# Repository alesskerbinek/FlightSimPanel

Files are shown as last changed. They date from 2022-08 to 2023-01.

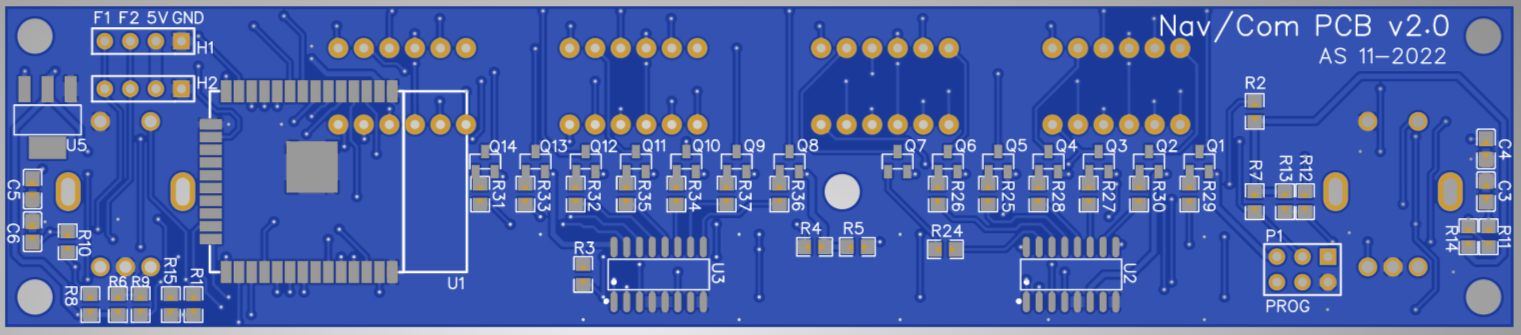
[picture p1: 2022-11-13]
Hardware/NavCom/PCB/v2/v2.0_Bottom.PNG

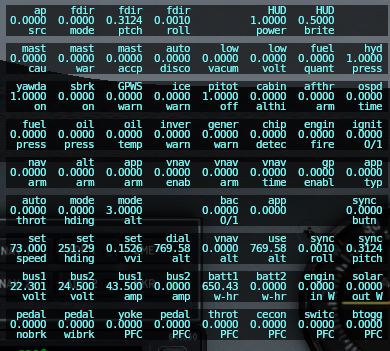
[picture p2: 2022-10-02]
Scratch/DATA2.JPG

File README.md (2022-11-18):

# FlightSimPanel

This is the main directory for FlightSimPanel project. For detailed description please read the [Wiki](https://github.com/alesskerbinek/FlightSimPanel/wiki) pages.

The directory structure is as follows:
<pre>
.
├── Scratch         # Ideas and notes
├── Hardware
│    ├── NavCom     # VOR/Radio/ADF/XPNDR unit
│    │    ├── PCB
│    │    │    ├── v1
│    │    │    └── v2
│    │    └── Case
│    ├── Audio*     # Audio Panel unit
│    │    ├── PCB*
│    │    └── Case*
│    └── Autopilot* # Autopilot Control unit
│         ├── PCB*
│         └── Case*
└── Software
     ├── NavCom     # VOR/Radio/ADF/XPNDR unit
     ├── Common     # Common files
     ├── Audio*     # Audio Panel unit
     └── Autopilot* # Autopilot Control unit
     
* - TODO
</pre>

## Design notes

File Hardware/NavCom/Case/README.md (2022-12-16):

In this directory we find Case/Housing related project files.

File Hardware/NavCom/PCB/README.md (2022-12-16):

In this directory we find PCB related project files.

PCB revisions are separated in multiple subdirectories.

You can preview Gerber files on: https://www.pcbway.com/project/OnlineGerberViewer.html

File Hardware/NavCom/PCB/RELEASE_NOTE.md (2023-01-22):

v1.0
* initial version

v2.0
* Increased clearance around holes (moving resistors)
* Extended width of power lines between I2C headers (due to daisy chaining)
* Renaming data lines on I2C headers to F1 & F2
* Buttons footprint changed to SMD that fits both switches and tactile pushbuttons
* Diode footprint modified to support bigger size component
* Button positions changed
* Added LED to tell status of unit (connected to sim)
* Additional bolt fix point in the middle of the board

v2.1
* minor fixes on the schematics only (comments and resistors R15, R38 values changed)

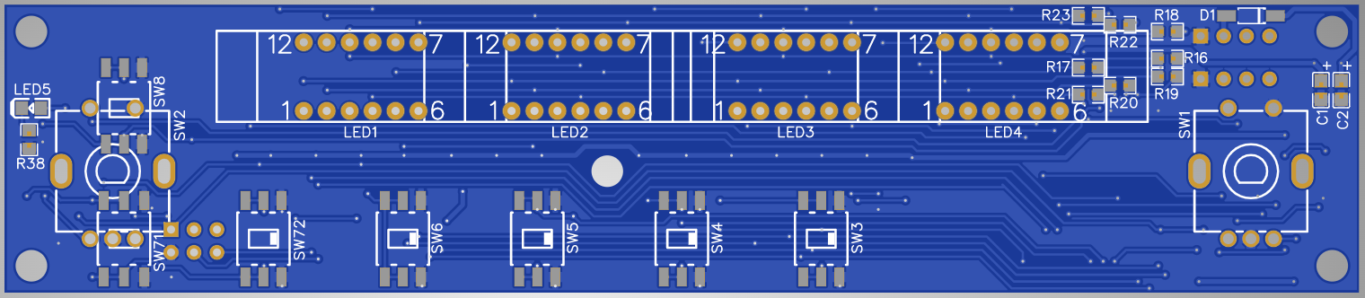
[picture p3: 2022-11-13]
Hardware/NavCom/PCB/v2/v2.0_Top.PNG

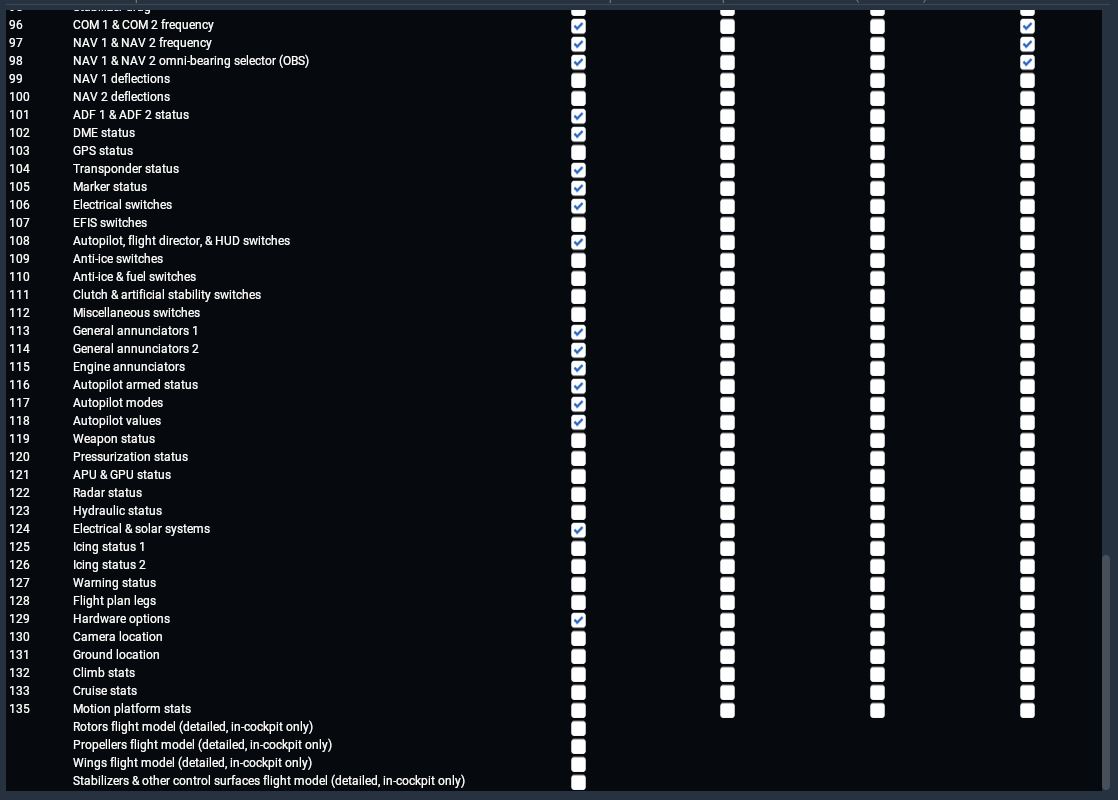
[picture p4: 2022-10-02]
Scratch/DATA0.JPG

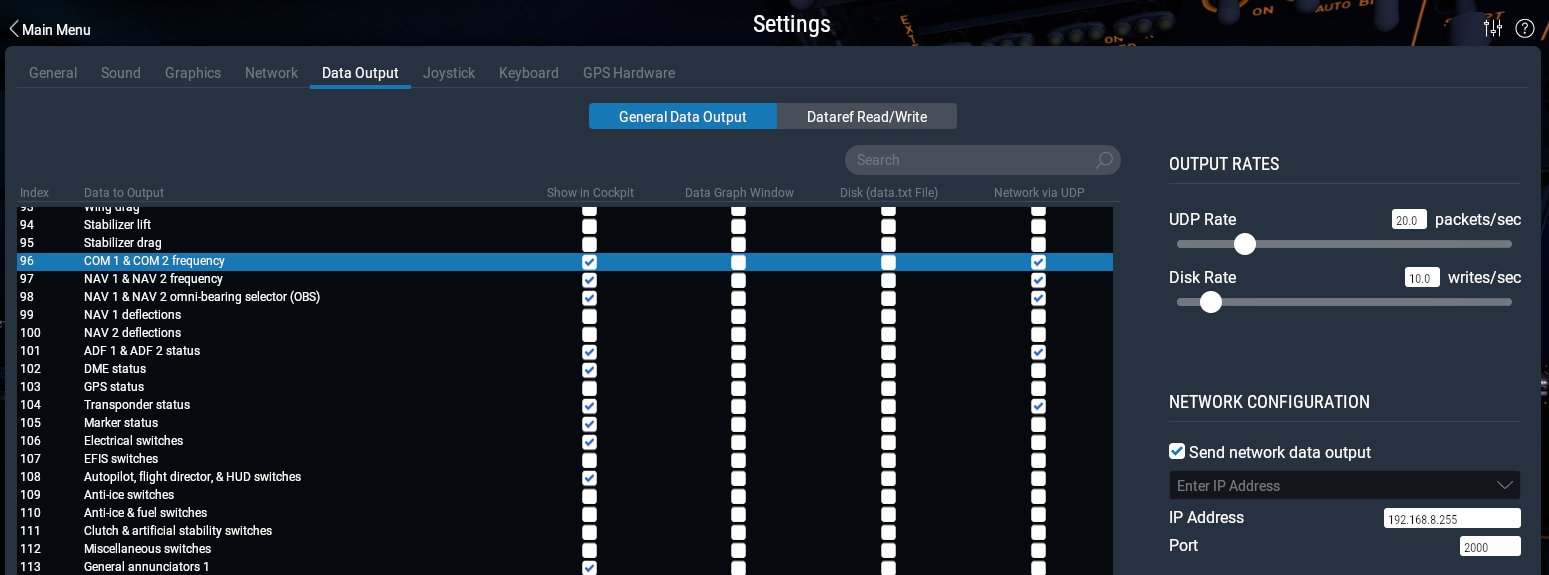
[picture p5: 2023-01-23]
Docu/Resource/data-config.PNG

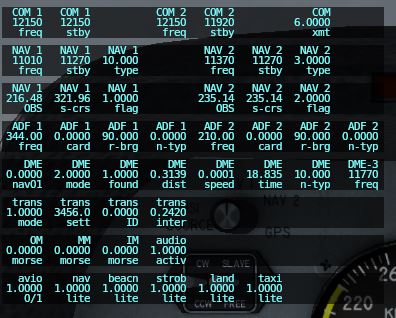
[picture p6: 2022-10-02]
Scratch/DATA1.JPG

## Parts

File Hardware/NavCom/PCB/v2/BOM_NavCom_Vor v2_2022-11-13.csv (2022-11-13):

ID | Name | Designator | Footprint | Quantity | Manufacturer Part | Manufacturer | Supplier | Supplier Part | Price
1 | 10u | C1,C2 | C0805 | 2
2 | 220n | C3,C4,C5,C6 | C0805 | 4
3 | 1N4007 | D1 | SOD-123_L2.8-W1.8-LS3.7-RD | 1 | 1N4007W | BLUE ROCKET | LCSC | C328592 | 0.011
4 | HDR-F-2.54 | H1,H2 | HDR-F-2.54_1X4 | 2 |  |  | LCSC | C239342 | 0.089
5 | 2481BS | LED1,LED2,LED3,LED4 | 7-SEGMENT_2481BS | 4 | MHDA3641SRBW | MEIHUA | LCSC | C401125 | 1.041
6 | LED-Red(0805) | LED5 | LED-0805 | 1 | 17-21SURC/S530-A2/TR8 | Everlight Elec | LCSC | C131244 | 0.02
7 | HDR-2.54-2X3P | P1 | HDR-F-2.54_2X3 | 1 | 2X3 2.54mm IDC Box | BOOMELE | LCSC | C11214 | 0.09
8 | BC807-40LVL | Q1,Q2,Q3,Q4,Q5,Q6,Q7,Q8,Q9,Q10,Q11,Q12,Q13,Q14 | SOT-23-3_L2.9-W1.3-P1.90-LS2.4-BR | 14 | BC807-40LVL | Nexperia | LCSC | C549409 | 0.024
9 | 10k | R1,R2,R3,R4,R5,R6,R7,R8,R9,R10,R11,R12,R13,R14,R15,R38 | R0805 | 16
10 | 220 | R16,R17,R18,R19,R20,R21,R22,R23 | R0805 | 8
11 | 1K | R24,R25,R26,R27,R28,R29,R30,R31,R32,R33,R34,R35,R36,R37 | R0805 | 14
12 | PEC11R | SW1,SW2 | SW-TH_PEC11R-4XXXF-SXXXX | 2 | PEC11R-4015F-S0024 | BOURNS | LCSC | C143789 | 1.67
13 | K8-5851E-L1 | SW3,SW4,SW5,SW6,SW8,SW71,SW72 | SW-TH_6P-L5.8-W5.8-P2.00-LS4.5-BL | 7 | K8-5851E-L1 | HRO | LCSC | C111760 | 0.2
14 | ESP32-WROOM-32D-H4 | U1 | WIFIM-SMD_ESP32-WROOM-32D | 1 | ESP32-WROOM-32D-H4 | ESPRESSIF 乐鑫 | LCSC | C3013936 | 3.336
15 | 74HC138D | U2,U3 | SOIC-16_L9.9-W3.9-P1.27-LS6.0-BL | 2 | 74HC138D | TOSHIBA(东芝) | LCSC | C2674688 | 0.147
16 | NCP1117ST33T3G | U5 | SOT-223-3_L6.5-W3.4-P2.30-LS7.0-BR | 1 | NCP1117ST33T3G | ON | LCSC | C26537 | 0.311

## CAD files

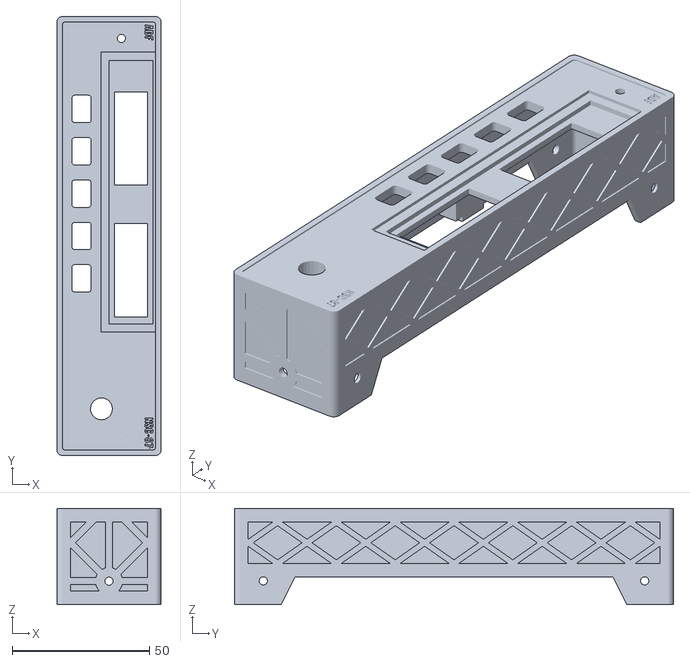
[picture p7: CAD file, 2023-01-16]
Hardware/NavCom/Case/ADF-case.stl
38.0 x 160.0 x 35.0

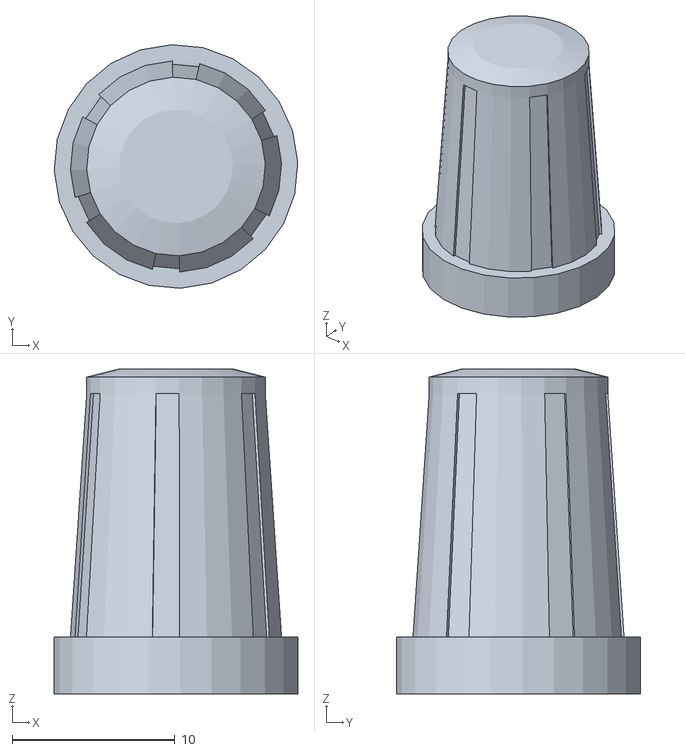
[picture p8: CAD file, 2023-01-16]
Hardware/NavCom/Case/Knob-empty.stl
15.0 x 15.0 x 20.0

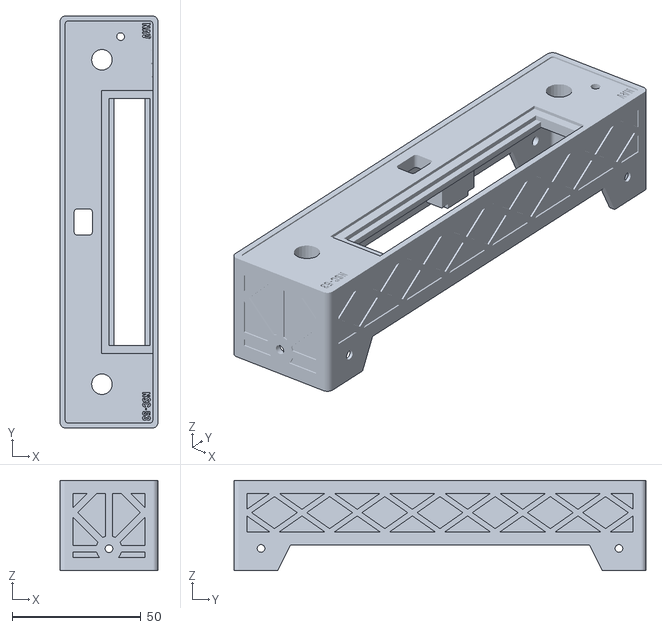
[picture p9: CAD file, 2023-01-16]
Hardware/NavCom/Case/NAV-case.stl
38.0 x 160.0 x 35.0

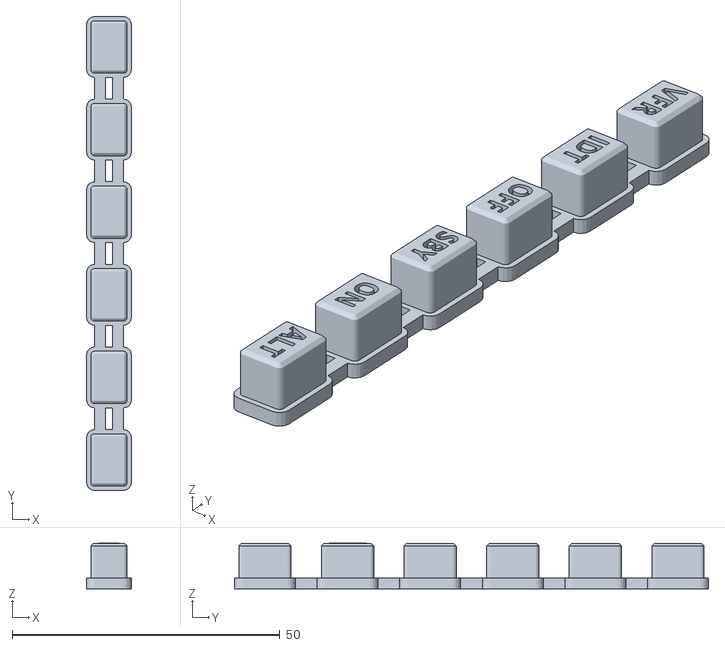
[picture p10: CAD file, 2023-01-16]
Hardware/NavCom/Case/XPNDR-buttons.stl
8.40 x 88.6 x 8.52

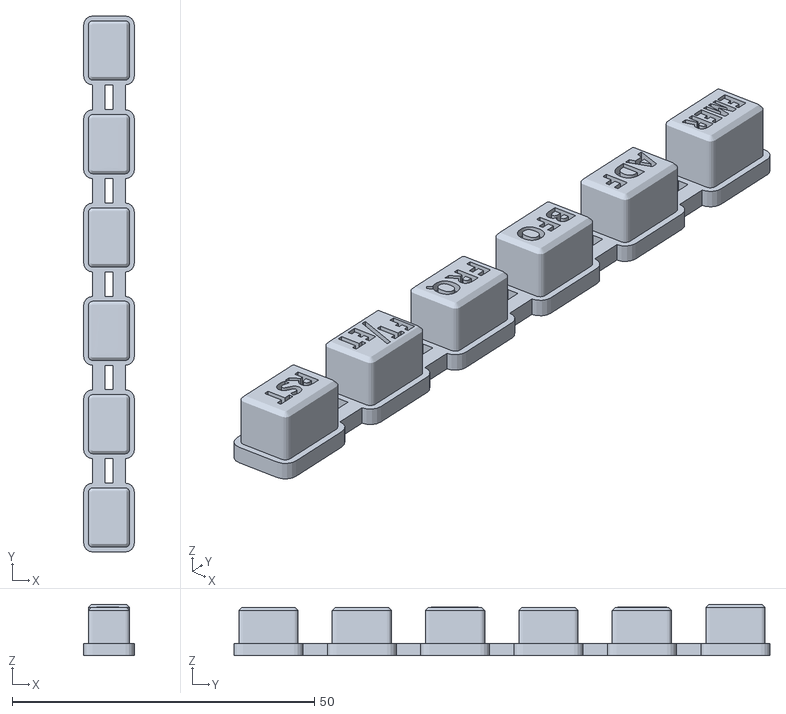
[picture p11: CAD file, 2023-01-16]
Hardware/NavCom/Case/ADF-buttons.stl
8.40 x 88.7 x 8.50

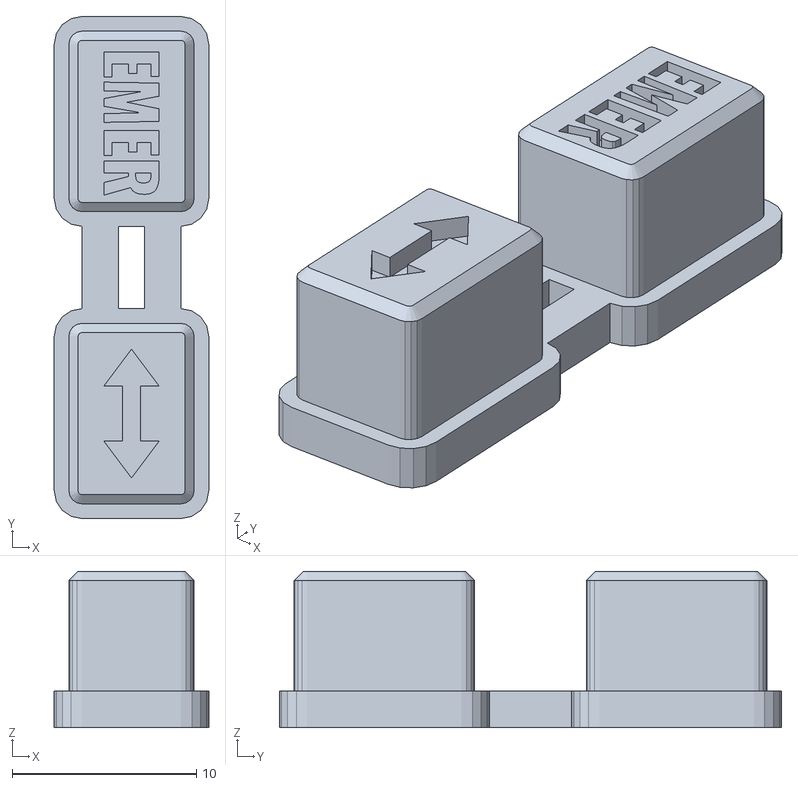
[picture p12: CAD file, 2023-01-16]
Hardware/NavCom/Case/COM-buttons.stl
8.40 x 27.3 x 8.50

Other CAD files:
Hardware/NavCom/Case/XPNDR-case.stl
Hardware/NavCom/Case/Knob-OBS.stl
Hardware/NavCom/Case/Knob-volume.stl
Hardware/NavCom/Case/COM-case.stl
Hardware/NavCom/Case/ADF-buttons.skp
Hardware/NavCom/Case/ADF-case.skp
Hardware/NavCom/Case/COM-buttons.skp
Hardware/NavCom/Case/COM-case.skp
Hardware/NavCom/Case/Knob-OBS.skp
Hardware/NavCom/Case/Knob-empty.skp
Hardware/NavCom/Case/Knob-volume.skp
Hardware/NavCom/Case/NAV-case.skp
Hardware/NavCom/Case/XPNDR-buttons.skp
Hardware/NavCom/Case/XPNDR-case.skp

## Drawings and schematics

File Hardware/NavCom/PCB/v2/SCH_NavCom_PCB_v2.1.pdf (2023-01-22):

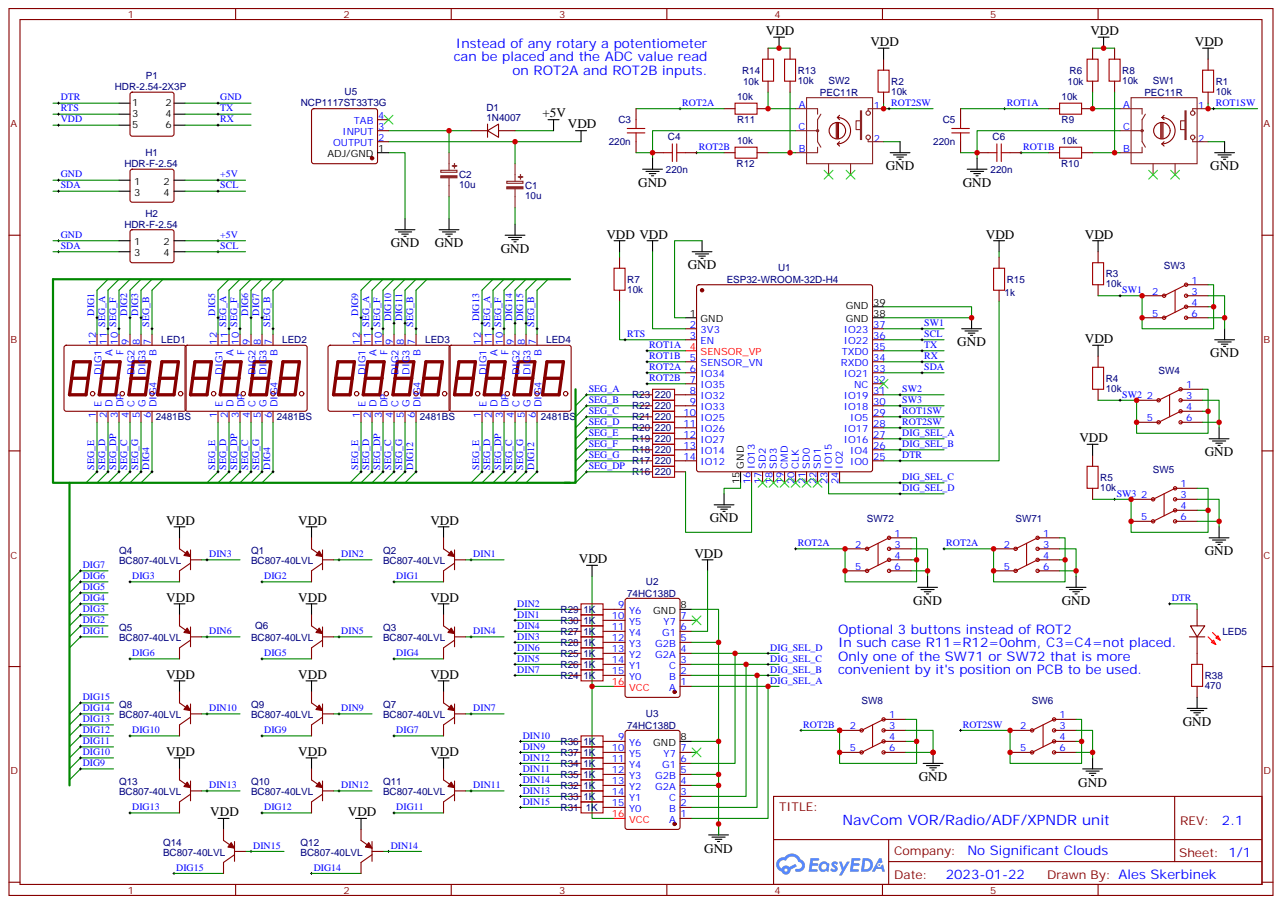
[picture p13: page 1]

Instead of any rotary a potentiometer
can be placed and the ADC value read

Optional 3 buttons instead of ROT2
In such case R11=R12=0ohm, C3=C4=not placed.
Only one of the SW71 or SW72 that is more
convenient by it's position on PCB to be used.

Company: No Significant Clouds

Drawn By: Ales Skerbinek

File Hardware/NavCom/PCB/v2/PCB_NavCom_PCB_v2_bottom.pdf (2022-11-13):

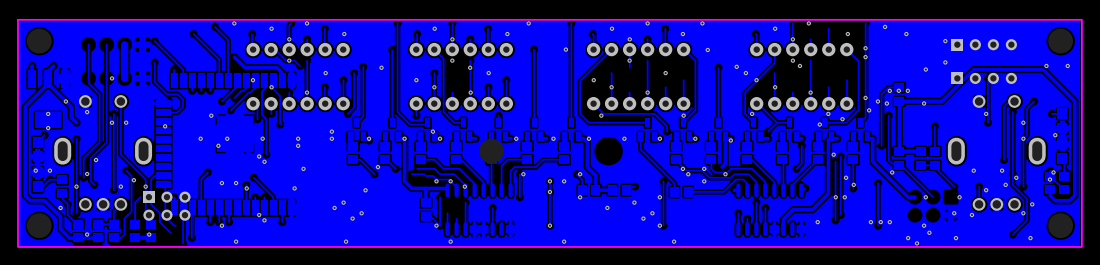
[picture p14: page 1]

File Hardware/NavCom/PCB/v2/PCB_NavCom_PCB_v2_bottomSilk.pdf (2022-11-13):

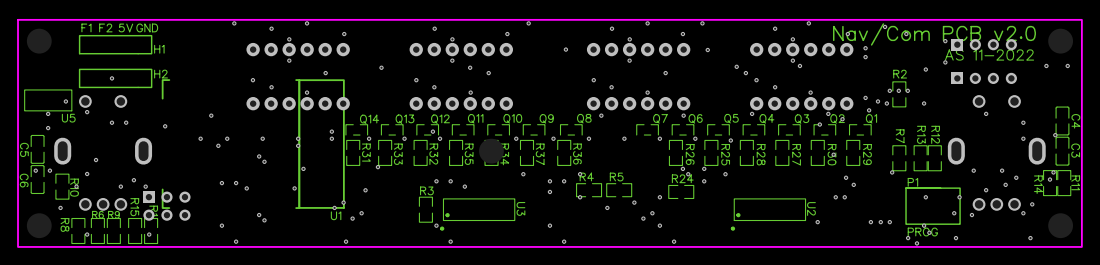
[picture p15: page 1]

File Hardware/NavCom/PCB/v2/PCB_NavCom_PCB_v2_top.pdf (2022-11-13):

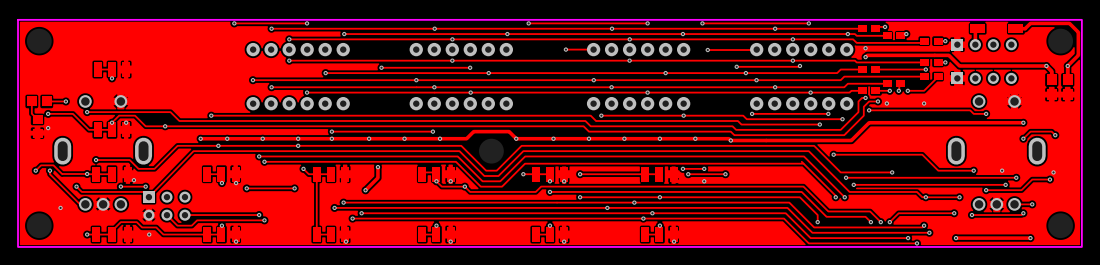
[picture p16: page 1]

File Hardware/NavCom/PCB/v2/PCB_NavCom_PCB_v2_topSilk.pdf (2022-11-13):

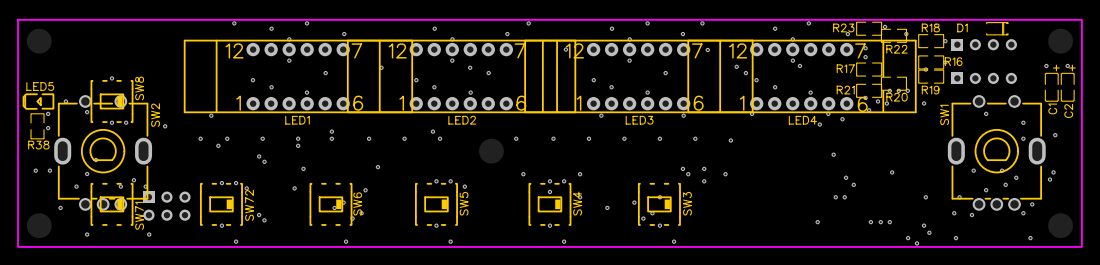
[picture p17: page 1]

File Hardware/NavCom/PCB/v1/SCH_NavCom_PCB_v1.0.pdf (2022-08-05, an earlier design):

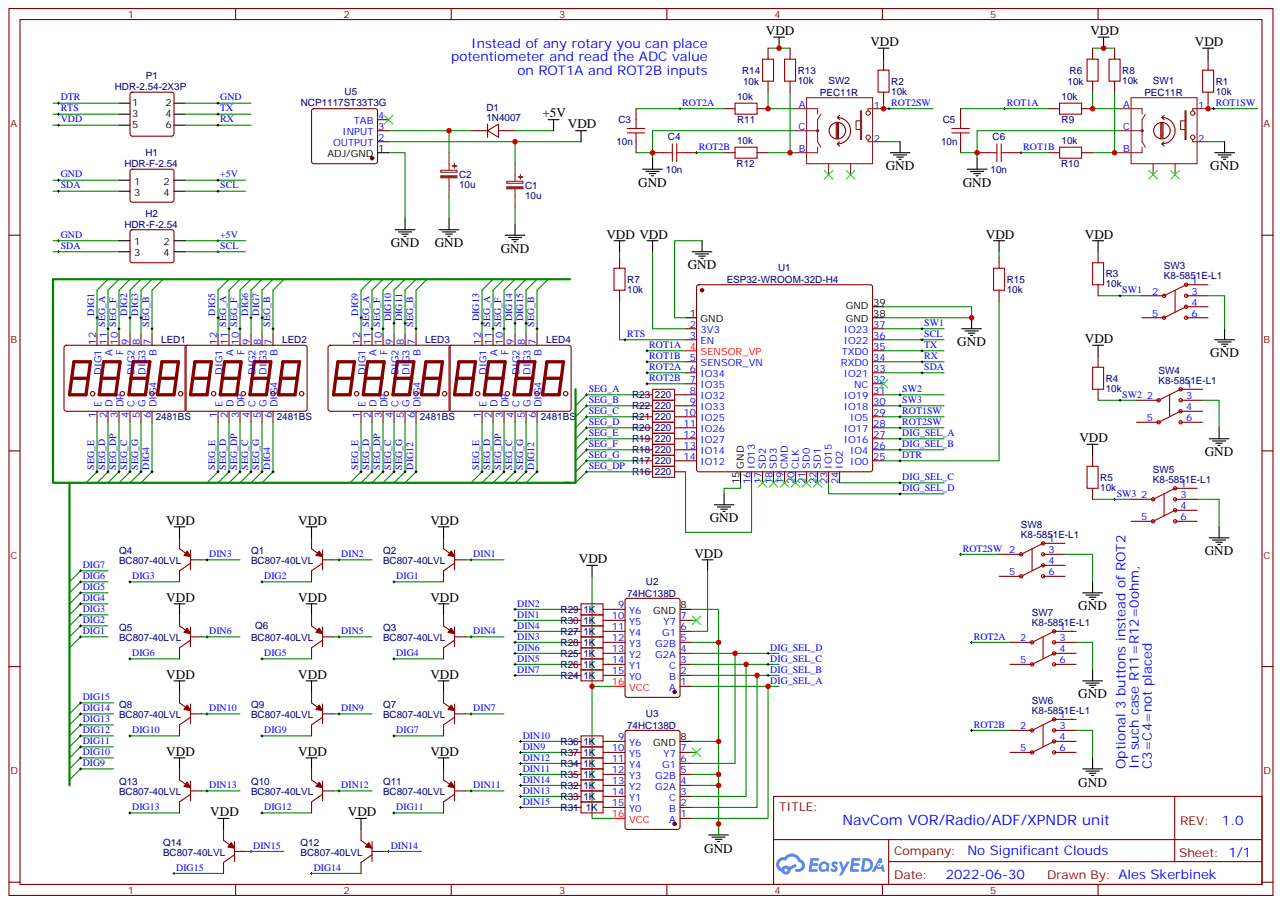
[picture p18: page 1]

Instead of any rotary you can place
potentiometer and read the ADC value

Optional 3 buttons instead of ROT2

Company: No Significant Clouds

Drawn By: Ales Skerbinek

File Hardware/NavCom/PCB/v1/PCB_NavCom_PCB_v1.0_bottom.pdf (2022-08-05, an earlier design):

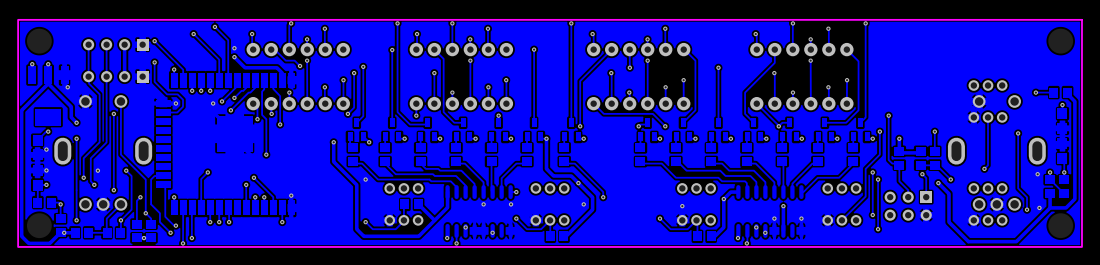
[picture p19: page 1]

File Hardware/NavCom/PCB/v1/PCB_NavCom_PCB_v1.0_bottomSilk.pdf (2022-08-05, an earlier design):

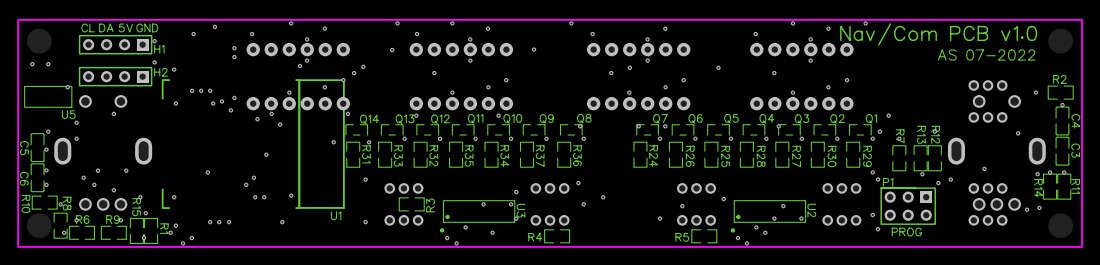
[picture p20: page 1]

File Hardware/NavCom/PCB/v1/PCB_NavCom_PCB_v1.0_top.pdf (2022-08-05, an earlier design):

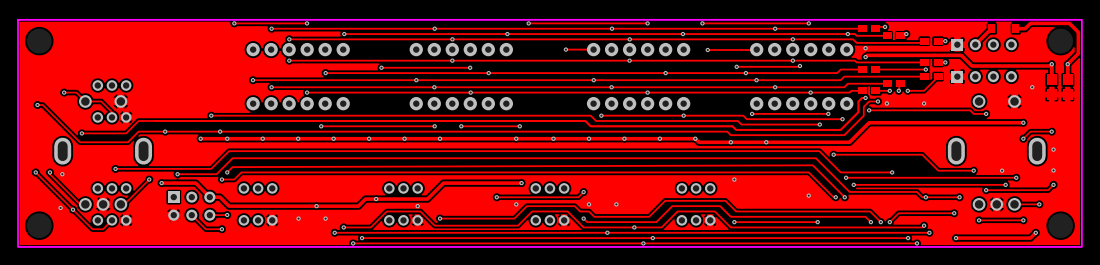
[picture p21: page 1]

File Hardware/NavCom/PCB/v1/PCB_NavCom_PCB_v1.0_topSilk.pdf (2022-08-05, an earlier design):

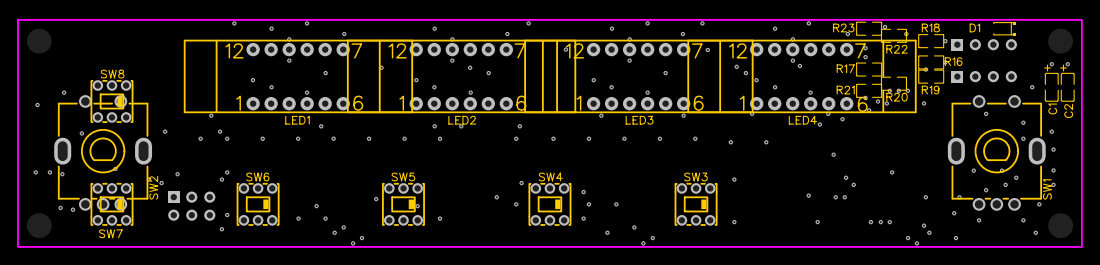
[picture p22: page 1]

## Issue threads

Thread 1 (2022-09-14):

NavCom PCB v2 revision

alesskerbinek, 2022-09-14:
To improve:
1. Clearance around holes (resistors)
2. Headers clearance (I2C)
3. Power lines between I2C headers width (extend due to daisy chaining)
4. Rename data lines on I2C headers to F1 & F2 or similar. Theoreticaly we can implement UART as well. Teoreticaly we can connect to external input output as well.
5. Buttons rotate or change for another type (SMD footprint that fits both switches and tactile pushbuttons)
6. Diode size
7. Rotary encoders capacitors/circuit
8. Switch 6 and 8 change + think about the position of switches (there are commands for turning nav/com on/off and adf supports 5 modes) - specify detailed functions of each unit now that we know commands. Test commands before.
9. LED to tell status of unit (connected to sim) - test if we can use GPIO0 (it has internal pull up if used as input. it is important that it is 0V during programming.)
10. Additional bolt fix point in the middle of the board

alesskerbinek, 2022-09-21:
* Switch 6 and 8 change + think about the position of switches (there are commands for turning nav/com on/off and adf supports 5 modes) - specify detailed functions of each unit now that we know commands. Test commands before.

alesskerbinek, 2022-09-21:
* (RGB) LED to tell status of unit (connected to sim/demo)

alesskerbinek, 2022-11-02:
Solved:
1.

alesskerbinek, 2022-11-05:
Solved: 5, 8, 9, 10

Closed 2022-11-13.

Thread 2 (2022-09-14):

NavCom housing

alesskerbinek, 2022-09-14:
Draw 3D model for NavCom houings (Radio, VOR, ADF, XPNDR) + buttons.

alesskerbinek, 2022-11-18:
Ordered prototype housing

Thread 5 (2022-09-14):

UDP client

alesskerbinek, 2022-09-14:
Implement UDP client for sending actions (key press commands) to simulator.

alesskerbinek, 2022-09-23:
#include <queue>
#include <cstring>

/**
* @brief Udp message types
*/
enum UdpDataType {
	dtUndefined = 0,
	dtDATA,
	dtDREF,
	dtCHAR,
	dtCMND,
	dtCount
};

/**
* @brief DataRefs that are being sent to X-Plane simulator
*/
enum DataRefs {
	drUndefined = 0,
	drCom1Freq,
};

/**
* @brief Commands that are being sent to X-Plane simulator
*/
enum Commands {
	cmUndefined = 0,
	cmLandingGear,
};

/**
* @brief Udp datatgram structure used for Tx queue.
* It does not contain whole datagram bytes but enums for individual
* commands/datarefs to save some memory.
*/
struct UdpDatagram {
	UdpDatagram(UdpDataType eTyp, uint32_t uiPar, uint32_t uiVal = 0)
	{
		m_eType = eTyp;
		m_uiValue = uiVal;
		m_uiParameter = uiPar;
	}

	UdpDatagram(UdpDataType eTyp, uint32_t uiPar, float fVal)
	{
		m_eType = eTyp;
		m_uiParameter = uiPar;
		memcpy(&m_uiValue, &fVal, sizeof(m_uiValue));
	}

	UdpDataType m_eType;
	uint32_t m_uiParameter;
	uint32_t m_uiValue;
};

//! UDP Transmit queue.
std::queue<UdpDatagram> m_qTX;

void SendUDP(char* pData, uint32_t uiSize)
{
	qDebug() << "TX:" << pData << uiSize;
}

/*** @brief Returns text representation for given DataRef type.
* @param dr DataRef type
* @return DataRef text
*/
const char* GetDataRefString(DataRefs dr)
{
	switch (dr) {
	case drCom1Freq:
		return "/sim/cockpit2/radios/actuators/com1_standby_frequency_hz[0]";
	default:
		return nullptr;
	}
}

/** * @brief Returns text representation for given Command type.
* @param cmd Command type
* @return Command text
*/
const char* GetCommandString(Commands cmd)
{
	switch (cmd) {
	case cmLandingGear:
		return "/sim/flight_controls/landing_gear_down";
	default:
		return nullptr;
	}
}

/**
* @brief Constructs DREF datagram from given attributes.
* @param uiValue 4 byte value
* @param eType DataRef type
*/
void SendDataRef(uint32_t uiValue, DataRefs eType)
{
	const char* pText = GetDataRefString(eType);
	if(pText)
	{
		char acBuffer[509];

		strncpy(acBuffer, "DREF0", 5);
		memcpy(&acBuffer[5], &uiValue, 4);
		memset(&acBuffer[9], 0x20, sizeof(acBuffer)-9); strncpy(&acBuffer[9], pText, sizeof(acBuffer)-9);

		SendUDP(acBuffer, 509);
	}
}

/**
* @brief Contructs CHAR datagram with given value
* @param uiValue keyboard key character
*/
void SendChar(uint8_t uiValue)
{
	char acBuffer[6];

	strncpy(acBuffer, "CHAR0", 5);
	acBuffer[5] = uiValue;

	SendUDP(acBuffer, 6);
}

/**
* @brief Constructs CMND datagram with given type.
* @param eType Command type
*/
void SendCommand(Commands eType)
{
	const char* pText = GetCommandString(eType);
	if(pText)
	{
		char acBuffer[100];

		strncpy(acBuffer, "CMND0", 5);
		strncpy(&acBuffer[5], pText, sizeof(acBuffer)-5);

		SendUDP(acBuffer, strlen(acBuffer));
	}
}

/**
* @brief Adds given datagram to transmit queue
* @param data datagram to be put on queue.
*/
void AddToTxQueue(UdpDatagram data)
{
	m_qTX.push(data);
}

/**
* @brief Returns the oldest datagram from transmit queue (FIFO).
* @return The oldest datagram
*/
UdpDatagram GetFromTxQueue()
{
	UdpDatagram sDatagram = m_qTX.front();
	m_qTX.pop();

	/**/
	switch (sDatagram.m_eType) {
	case dtDATA:
		break;
	case dtDREF:
		SendDataRef(sDatagram.m_uiValue, static_cast<DataRefs>(sDatagram.m_uiParameter));
		break;
	case dtCHAR:
		SendChar(sDatagram.m_uiValue & 0xFF);
		break;
	case dtCMND:
		SendCommand(static_cast<Commands>(sDatagram.m_uiParameter));
		break;
	default:
		break;
	}
	/**/

	return sDatagram;
}

 AddToTxQueue(UdpDatagram(UdpDataType::dtDREF, DataRefs::drCom1Freq, (uint32_t)0x462AA001));
 AddToTxQueue(UdpDatagram(UdpDataType::dtCHAR, 0, (uint32_t)0x41));
 AddToTxQueue(UdpDatagram(UdpDataType::dtCMND, Commands::cmLandingGear));
 GetFromTxQueue();
 GetFromTxQueue();
 GetFromTxQueue();

Closed 2022-10-02.

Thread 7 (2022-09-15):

Components for Autopilot PCB

alesskerbinek, 2022-09-15:
Order:
* scrolling encoder
* scroll wheel
* square LEDs
* headers
* square and hot melt nuts

(at the same time order car key case x2)

Closed 2022-10-11.

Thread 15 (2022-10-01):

Implement Demo mode

alesskerbinek, 2022-10-01:
When device is not connected to X-Plane enter demo mode and set active/passive values in model on your own.

Need to implement mechanism for detecting connection with X-Plane as well. Something simple like checking incoming data and declare comm fail if no incoming data in some inteval.

Closed 2022-10-04.

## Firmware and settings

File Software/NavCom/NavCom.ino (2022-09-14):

#include "NavCom.h"

NavCom app;

//-----------------------------------------------------------------------------

void setup()
{
    app.Initialize();
    app.Run();

    // Can't reach this point...
    return;
}

//-----------------------------------------------------------------------------

void loop()
{
    // Can't reach this point...
}

//-----------------------------------------------------------------------------

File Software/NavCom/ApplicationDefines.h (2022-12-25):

#ifndef APPLICATION_DEFINES_H
#define APPLICATION_DEFINES_H

#include <stdint.h>
#include <stddef.h>
#include <Arduino.h>

// --------------------------------------------------------------------------

#ifndef BUILD_NUMBER
#define BUILD_NUMBER 0
#endif

#ifndef SW_VERSION_MAJOR
#define SW_VERSION_MAJOR	0
#endif

#ifndef SW_VERSION_MINOR
#define	SW_VERSION_MINOR	9
#endif

// --------------------------------------------------------------------------

#define PROJECT_NAME    "NavCom"

// Inputs
#define ROTARY_COUNT    2
#define BUTTON_COUNT    7

// Outputs
#define DIGIT_COUNT     12

// --------------------------------------------------------------------------

// Connection status LED
#define PIN_CONN 0

// NavCom Button pins
#define PIN_SW1 5
#define PIN_SW2 17
#define PIN_SW3 23
#define PIN_SW4 19
#define PIN_SW5 18

// NavCom Rotary Knob input pins
#define ROT1_B 39
#define ROT1_A 36
#define ROT2_B 35
#define ROT2_A 34

// NavCom Digit Select bus pins
#define DIG_SEL_A 16
#define DIG_SEL_B 4
#define DIG_SEL_C 2
#define DIG_SEL_D 15

// NavCom Digit Data bus pins
#define SEG_A 32
#define SEG_B 33
#define SEG_C 25
#define SEG_D 26
#define SEG_E 27
#define SEG_F 14
#define SEG_G 12
#define SEG_DP 13

// NavCom 7-segment digit addresses
#define DIG_X 4
#define DIG_Y 12
#define DIG_1 5
#define DIG_2 6
#define DIG_3 3
#define DIG_4 1
#define DIG_5 2
#define DIG_6 0
#define DIG_7 13
#define DIG_8 14
#define DIG_9 11
#define DIG_10 9
#define DIG_11 10
#define DIG_12 8

// 7-segment characters
//   A
// F   B
//   G
// E   C
//   D   DP
#define CH_0 0xC0
#define CH_1 0xF9
#define CH_2 0xA4
#define CH_3 0xB0
#define CH_4 0x99
#define CH_5 0x92
#define CH_6 0x82
#define CH_7 0xF8
#define CH_8 0x80
#define CH_9 0x90
#define CH_A 0x88
#define CH_B 0x83
#define CH_C 0xC6
#define CH_D 0xA1
#define CH_E 0x86
#define CH_F 0x8E
#define CH_G 0x82
#define CH_H 0x89
#define CH_I 0xF9
#define CH_L 0xC7
#define CH_N 0xAB
#define CH_O 0xC0
#define CH_S 0x92
#define CH_T 0x87
#define CH_U 0xC1
#define CH_V 0xC1 //0x8D
#define CH_Y 0x91
#define CH_Z 0xA4
#define CH_SPACE 0xFF

#define DECIMAL_POINT   0x7F

// --------------------------------------------------------------------------

//! Settings structure
typedef  struct {
    uint32_t uiSerialNumber;    // 4 bytes
    uint32_t uiActiveValue;     // 4 bytes
    uint32_t uiStandbyValue;    // 4 bytes
    uint8_t  uiUnitType;        // 1 byte
    char     acWiFiSSID[33];    // 33 bytes
    char     acWiFiPass[33];    // 33 bytes
    uint8_t  auiFree0;          // FREE SPACE
    uint16_t uiUdpListenPort;   // 2 bytes
    uint16_t uiUdpRemotePort;   // 2 bytes
    uint32_t uiUdpRemoteIP;     // 4 bytes
    uint16_t uiOBS;             // 2 bytes
    uint16_t uiHDG;             // 2 bytes
    uint8_t  auiFree[164];      // FREE SPACE (sum of structure = 256 bytes)
} settings_t;

//! Unit types
typedef  enum {
    utUndefined = 0,
    utCom1,
    utCom2,
    utVOR1,
    utVOR2,
    utADF1,
    utADF2,
    utXPNDR
} UnitTypes;

//! Unit modes
typedef  enum {
    xmUndefined = 0,
    // General
    gmOff,
    gmOn,
    // XPNDR
    xmSby,
    xmAlt,
    // ADF
    amFrq,
    amFlT,
    amElT,
} UnitModes;

// --------------------------------------------------------------------------

#endif

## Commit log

2022-08-05 Add NavCom project files
    [BOM_PCB_NavCom_PCB_v1.0_2022-08-01.csv]
2022-08-05 Added NavCom PCB project files
    [BOM_PCB_NavCom_PCB_v1.0_2022-08-01.csv]
2022-09-14 NavCom PCB files moved to Hardware directory
    [BOM_PCB_NavCom_PCB_v1.0_2022-08-01.csv]
2022-09-15 Fix for erratic rotary encoder behavior
    [Input.cpp]
2022-09-17 Working on UDP listener and sender
    Implemented WiFi connecting state machine (need to test border cases)
    + implemented UDP listener (need to add parser)
    + implemented UDP sending methods (need to further test)
    + Added network settings
    + Minor stability fix in ConfigPortNavCom
    [ApplicationDefines.h]
2022-09-29 Fixes to CMND, CHAR and DREF messages. CMND tested working.
    [Input.cpp]
2022-10-04 Working on Xpndr features + Demo/Connected mode implemented (also the status LED) closes #15
2022-10-09 Process 1000Hz implemented with micros timer (closes #16 )
2022-10-09 Button press, long-press and release events distinguished + working on xpndr features
2022-11-12 Initial version of components and casings for all 4 NavCom units
    [NavCom.skp]
2022-11-13 NavCom PCB v2.0 files
    [BOM_NavCom_Vor v2_2022-11-13.csv, BOM_PCB_NavCom_PCB_v1.0_2022-08-01.csv]
2022-11-18 NavCom 3D models completed
    [NavCom Buttons.skp, NavCom Buttons.stl, NavCom Test Prototype.skp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]
2022-12-09 ADF timer modes implemented + minor changes in value editing user experiences on all unit types
2022-12-16 Fix for Setting VOR2 frequencies
    [Input.cpp]
2022-12-25 OBS and HDG bug implemented for VOR unit
    [ApplicationDefines.h, Input.cpp, Output.cpp]
2023-01-16 Added case 3d models
    [ADF-buttons.skp, ADF-buttons.stl, ADF-case.skp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]
2023-01-22 minor modifications on NavCom schematics
